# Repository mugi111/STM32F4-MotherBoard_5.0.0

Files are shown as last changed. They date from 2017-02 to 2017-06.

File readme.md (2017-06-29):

### 概要
1. STM32F4-MotherBoard_5.0.0  
STM32F407VGのマザーボード  
回路図，実体配線図
KiCADプロジェクト

2. RCsemiSTM32F4_Ver400
STM32F4MBライブラリ  
使用ライブラリ:SPD(Standard Peripheral Driver)  
使用言語:C

3. RCsemiSTM32F4_Ver500
STM32F4MBライブラリ  
使用ライブラリ:HAL Driver  
使用言語:C++

|STM32F4MB500|個数||
|---|-----|---|
|ADC |1 |BOXHEADER |
|CAN |2 |RJ45 |
|RS232C |2 |RJ12 |
|DisitalIO|2 |BOXHEADER |
|PushSW |1 |DTS-6 |
|RotarySW |1 | |
|LED |1 | |
|MicroSD  |1 | |

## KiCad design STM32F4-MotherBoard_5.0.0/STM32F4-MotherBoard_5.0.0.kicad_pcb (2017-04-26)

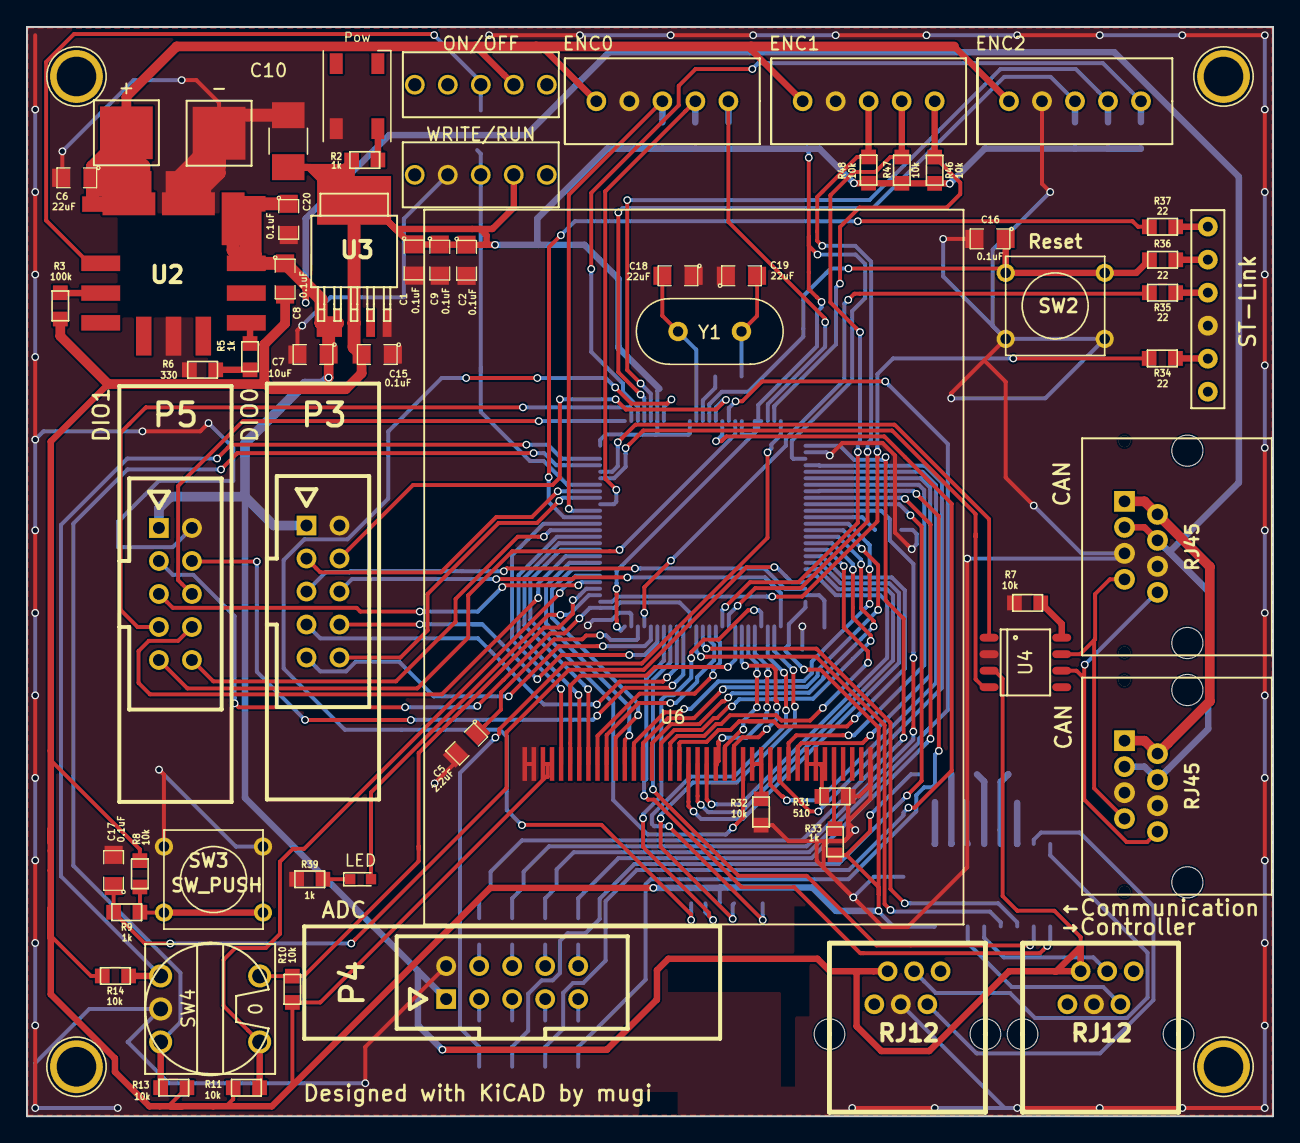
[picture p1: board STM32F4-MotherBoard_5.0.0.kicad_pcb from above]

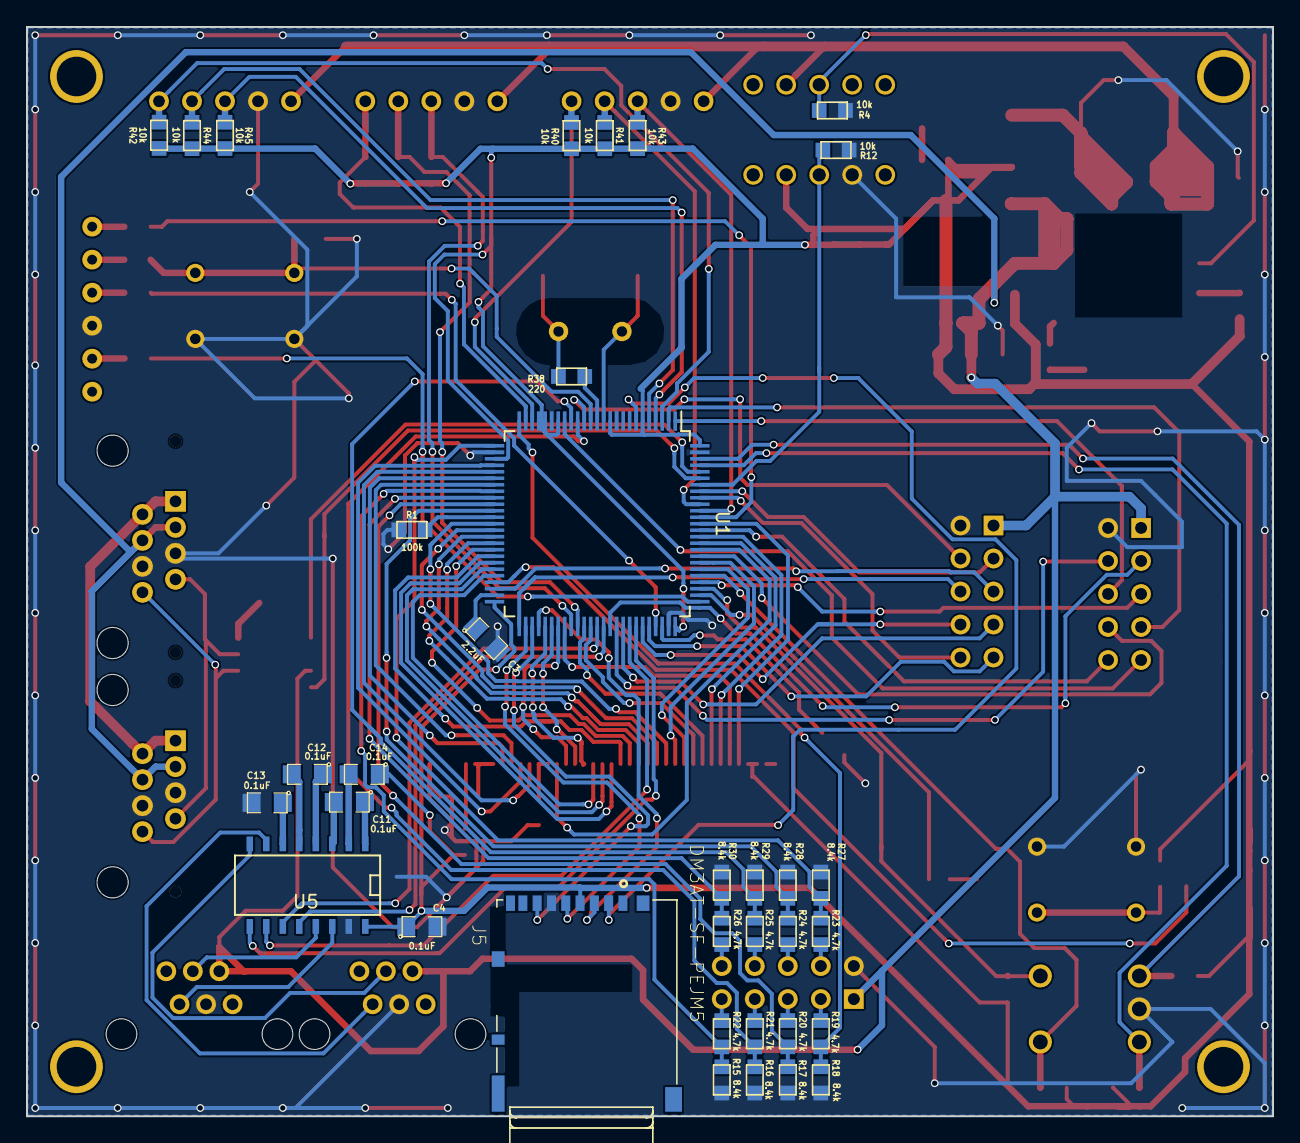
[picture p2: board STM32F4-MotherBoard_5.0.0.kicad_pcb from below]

Board: 2 copper layers, 95.9 x 83.8 mm, 96 parts (35 on the bottom side), 125 nets.

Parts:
+: VCC; 1Pin
-: GND; 1Pin
C1, C2, C4, C8, C9, C11, C12, C13, C14, C15, C16, C17, C20: 0.1uF; SM0805_EXP0.5mm
C3, C5: 2.2uF; SM0805_EXP0.5mm
C6, C18, C19: 22uF; SM0805_EXP0.5mm
C7: 10uF; SM0805_EXP0.5mm
C10: 47uF; C_1210_HandSoldering
CAN: RJ45; 7810-8P8C
CAN#2: RJ45; 7810-8P8C
ENC0: ENC0; XA-5
ENC1: ENC1; XA-5
ENC2: ENC2; XA-5
J5: DM3AT-SF-PEJM5; HRS_DM3AT-SF-PEJM5
LED: LED_0603
ON/OFF: ON/OFF; SW_TOGGLE_5P
P3: DIO0; RA-H101TD
P4: ADC; RA-H101TD
P5: DIO1; RA-H101TD
Pow: Power; LED_WS2812B-PLCC4
R1, R3: 100k; SM0603_EXP0.5mm
R2, R5, R9, R33, R39: 1k; SM0603_EXP0.5mm
R4, R7, R8, R10, R11, R12, R13, R14, R32, R40, R41, R42, R43, R44, R45, R46, R47, R48: 10k; SM0603_EXP0.5mm
R6: 330; SM0603_EXP0.5mm
R15, R16, R17, R18, R27, R28, R29, R30: 8.4k; SM0603_EXP0.5mm
R19, R20, R21, R22, R23, R24, R25, R26: 4.7k; SM0603_EXP0.5mm
R31: 510; SM0603_EXP0.5mm
R34, R35, R36, R37: 22; SM0603_EXP0.5mm
R38: 220; SM0603_EXP0.5mm
ST-Link: SWD; PinHeader-6
SW2: Reset; SW_PUSH
SW3: SW_PUSH
SW4: SW_ROTARY; RotarySW
U1: STM32F407VG; LQFP-100_14x14mm_Pitch0.5mm
U2: OKL-T6-W12
U3: PQ033EZ1H; PQ033EZ1HZ
U4: MCP2551-I/SN; SO-8
U5: ADM3202; SO-16-N
U6: AS021350D; ASO21350D
WRITE/RUN: WRITE/RUN; SW_TOGGLE_5P
Y1: 8MHz; Crystal_HC49-U_Vertical
←Communication: RJ12; MODULAR-JACK_6P6C
→Controller: RJ12; MODULAR-JACK_6P6C

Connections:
+3V3: C1.1, C2.1, C4.1, C8.2, C9.1, C10.2, C14.1, C15.2, J5.4, R2.1, R3.1, R8.1, R10.1, R11.1, R13.1, R14.1, R33.2, R40.1, R41.1, R42.1, R43.1, R44.1, R45.1, R46.1, R47.1, R48.1, U1.6, U1.11, U1.19, U1.21, U1.22, U1.28, U1.50, U1.75, U1.100, U3.3, U5.16, U6.3, U6.4, WRITE/RUN.2
+5V: C7.1, C8.1, C20.1, CAN.3, CAN.4, CAN#2.3, CAN#2.4, P3.1, P4.1, P5.1, U2.4, U2.5, U3.1, U3.2, U4.3, ←Communication.2, →Controller.2
+12V: +.1, C6.1, ENC0.1, ENC1.1, ENC2.1, ON/OFF.4, U2.2
+12VA: CAN.1, CAN.2, CAN#2.1, CAN#2.2
ADC0: R18.1, R19.2, U1.25
ADC1: R23.1, R27.1, U1.26
ADC2: R17.1, R20.2, U1.35
ADC3: R24.1, R28.1, U1.36
ADC4: R16.1, R21.2, U1.16
ADC5: R25.1, R29.1, U1.17
ADC6: R15.1, R22.2, U1.33
ADC7: R26.1, R30.1, U1.34
CAN_RX: U1.95, U4.4
CAN_TX: U1.96, U4.1
CS: U1.88, U6.5
DIO0_0: P3.3, U1.93
DIO0_1: P3.4, U1.15
DIO0_2: P3.5, U1.48
DIO0_3: P3.6, U1.51
DIO0_4: P3.7, U1.67
DIO0_5: P3.8, U1.70
DIO0_6: P3.9, U1.71
DIO0_7: P3.10, U1.92
DIO1_0: P5.3, U1.65
DIO1_1: P5.4, U1.66
DIO1_2: P5.5, U1.79
DIO1_3: P5.6, U1.1
DIO1_4: P5.7, U1.2
DIO1_5: P5.8, U1.83
DIO1_6: P5.9, U1.18
DIO1_7: P5.10, U1.87
ENC0_A: ENC0.3, R43.2, U1.90
ENC0_B: ENC0.4, R41.2, U1.91
ENC0_Z: ENC0.5, R40.2, U1.23
ENC1_A: ENC1.3, R48.2, U1.59
ENC1_B: ENC1.4, R47.2, U1.60
ENC1_Z: ENC1.5, R46.2, U1.24
ENC2_A: ENC2.3, R45.2, U1.4
ENC2_B: ENC2.4, R44.2, U1.5
ENC2_Z: ENC2.5, R42.2, U1.3
FSMC_D0: U1.61, U6.9
FSMC_D1: U1.62, U6.10
FSMC_D2: U1.81, U6.11
FSMC_D3: U1.82, U6.12
FSMC_D4: U1.38, U6.13
FSMC_D5: U1.39, U6.14
FSMC_D6: U1.40, U6.15
FSMC_D7: U1.41, U6.16
FSMC_D8: U1.42, U6.17
FSMC_D9: U1.43, U6.18
FSMC_D10: U1.44, U6.19
FSMC_D11: U1.45, U6.20
FSMC_D12: U1.46, U6.21
FSMC_D13: U1.55, U6.22
FSMC_D14: U1.56, U6.23
FSMC_D15: U1.57, U6.24
GND: -.1, C1.2, C2.2, C3.2, C4.2, C5.2, C6.2, C7.2, C9.2, C10.1, C13.2, C15.1, C16.2, C17.2, C18.1, C19.1, C20.2, CAN.5, CAN.6, CAN#2.5, CAN#2.6, ENC0.2, ENC1.2, ENC2.2, J5.6, P3.2, P4.2, P5.2, Pow.1, R1.2, R4.2, R6.2, R7.2, R12.2, R15.2, R16.2, R17.2, R18.2, R27.2, R28.2, R29.2, R30.2, R31.2, R32.2, R39.2, ST-Link.3, SW2.2, SW3.1, SW4.4, U1.10, U1.20, U1.27, U1.74, U1.99, U2.3, U2.7, U3.5, U4.2, U5.15, U6.1, U6.2, U6.39, WRITE/RUN.4, ←Communication.3, →Controller.3
LED: LED.2, U1.77
NRST: C16.1, R36.1, SW2.1, U1.14
unnamed: C3.1, U1.49
unnamed: C5.1, U1.73
unnamed: C11.1, U5.1
unnamed: C11.2, U5.3
unnamed: C12.1, U5.4
unnamed: C12.2, U5.5
unnamed: C13.1, U5.6
unnamed: C14.2, U5.2
unnamed: C19.2, R38.1, Y1.2
unnamed: Pow.2, R2.2
unnamed: LED.1, R39.1
unnamed: CAN.7, CAN#2.7, U4.7
unnamed: CAN.8, CAN#2.8, U4.6
unnamed: U5.13, →Controller.4
unnamed: U5.14, →Controller.5
unnamed: U5.8, ←Communication.4
unnamed: U5.7, ←Communication.5
unnamed: P4.3, R19.1
unnamed: P4.4, R23.2
unnamed: P4.5, R20.1
unnamed: P4.6, R24.2
unnamed: P4.7, R21.1
unnamed: P4.8, R25.2
unnamed: P4.9, R22.1
unnamed: P4.10, R26.2
unnamed: R34.2, ST-Link.2
unnamed: R35.2, ST-Link.4
unnamed: R36.2, ST-Link.5
unnamed: R37.2, ST-Link.6
unnamed: R1.1, U1.37
unnamed: R3.2, U2.10
unnamed: ON/OFF.3, R4.1, U2.1
unnamed: R5.1, U2.6
unnamed: R5.2, R6.1
unnamed: R7.1, U4.8
unnamed: R8.2, R9.2, SW3.2
unnamed: R31.1, U6.32, U6.33, U6.34
unnamed: R32.1, U6.26, U6.27
unnamed: R33.1, U6.35
OSC_IN: C18.2, U1.12, Y1.1
OSC_OUT: R38.2, U1.13
PushSW: C17.1, R9.1, U1.47
RD: U1.85, U6.8
RS: U1.58, U6.6
RS-232(Controller)_RX: U1.64, U5.12
RS-232(Controller)_TX: U1.63, U5.11
RS-232(PC)_RX: U1.69, U5.9
RS-232(PC)_TX: U1.68, U5.10
RST: U1.84, U6.25
RotarySW0: R10.2, SW4.1, U1.78
RotarySW1: R11.2, SW4.2, U1.80
RotarySW2: R13.2, SW4.3, U1.97
RotarySW3: R14.2, SW4.5, U1.98
SPI_CS: J5.2, U1.7
SPI_MISO: J5.7, U1.53
SPI_MOSI: J5.3, U1.54
SPI_SCK: J5.5, U1.52
SWCLK: R34.1, U1.76
SWDIO: R35.1, U1.72
SWO: R37.1, U1.89
WR: U1.86, U6.7
Write: R12.1, U1.94, WRITE/RUN.3
XL: U1.29, U6.29
XR: U1.31, U6.31
YB: U1.30, U6.28
YT: U1.32, U6.30

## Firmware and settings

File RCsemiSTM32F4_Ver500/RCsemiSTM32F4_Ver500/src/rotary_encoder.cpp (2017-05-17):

/*
 * rotary_encoder.cpp
 *
 *  Created on: 2017/03/07
 *      Author: mugi111
 */

#include "rotary_encoder.h"
#include <stm32f4xx_hal.h>
#include <stm32f4xx_hal_rcc.h>
#include <stm32f4xx_hal_gpio.h>
#include <stm32f4xx_hal_tim.h>

namespace RCsemi{

	rotary_encoder::rotary_encoder(int ch)
	{
		m_ch = ch;

		if(ch == 0){
			__HAL_RCC_GPIOB_CLK_ENABLE();
			__HAL_RCC_TIM3_CLK_ENABLE();

			GPIO_InitTypeDef GPIO_InitStructure;
			GPIO_InitStructure.Mode = GPIO_MODE_AF_PP;
			GPIO_InitStructure.Pin = GPIO_PIN_4 | GPIO_PIN_5;
			GPIO_InitStructure.Pull = GPIO_NOPULL;
			GPIO_InitStructure.Speed = GPIO_SPEED_FREQ_VERY_HIGH;
			GPIO_InitStructure.Alternate = GPIO_AF2_TIM3;

			HAL_GPIO_Init(GPIOB, &GPIO_InitStructure);

			TIM_Encoder_InitTypeDef Encoder_InitStructure;
			Encoder_InitStructure.EncoderMode = TIM_ENCODERMODE_TI12;
			Encoder_InitStructure.IC1Filter = 0;
			Encoder_InitStructure.IC1Polarity = TIM_ICPOLARITY_RISING;
			Encoder_InitStructure.IC1Selection = TIM_ICSELECTION_DIRECTTI;
			Encoder_InitStructure.IC1Prescaler = TIM_ICPSC_DIV1;
			Encoder_InitStructure.IC2Filter = 0;
			Encoder_InitStructure.IC2Polarity = TIM_ICPOLARITY_RISING;
			Encoder_InitStructure.IC2Selection = TIM_ICSELECTION_DIRECTTI;
			Encoder_InitStructure.IC2Prescaler = TIM_ICPSC_DIV1;

			TIM_HandleTypeDef htim3;
			htim3.Instance = TIM3;
			htim3.Init.Prescaler = 0;
			htim3.Init.CounterMode = TIM_COUNTERMODE_UP;
			htim3.Init.Period = 0;
			htim3.Init.ClockDivision = TIM_CLOCKDIVISION_DIV1;

			HAL_TIM_Encoder_Init(&htim3, &Encoder_InitStructure);
			HAL_TIM_Encoder_Start(&htim3, TIM_CHANNEL_ALL);

		}else if(ch == 1){
			__HAL_RCC_GPIOD_CLK_ENABLE();
			__HAL_RCC_TIM4_CLK_ENABLE();

			GPIO_InitTypeDef GPIO_InitStructure;
			GPIO_InitStructure.Mode = GPIO_MODE_AF_PP;
			GPIO_InitStructure.Pin = GPIO_PIN_12 | GPIO_PIN_13;
			GPIO_InitStructure.Pull = GPIO_NOPULL;
			GPIO_InitStructure.Speed = GPIO_SPEED_FREQ_VERY_HIGH;
			GPIO_InitStructure.Alternate = GPIO_AF2_TIM4;

			HAL_GPIO_Init(GPIOD, &GPIO_InitStructure);

			TIM_Encoder_InitTypeDef Encoder_InitStructure;
			Encoder_InitStructure.EncoderMode = TIM_ENCODERMODE_TI12;
			Encoder_InitStructure.IC1Filter = 0;
			Encoder_InitStructure.IC1Polarity = TIM_ICPOLARITY_RISING;
			Encoder_InitStructure.IC1Selection = TIM_ICSELECTION_DIRECTTI;
			Encoder_InitStructure.IC1Prescaler = TIM_ICPSC_DIV1;
			Encoder_InitStructure.IC2Filter = 0;
			Encoder_InitStructure.IC2Polarity = TIM_ICPOLARITY_RISING;
			Encoder_InitStructure.IC2Selection = TIM_ICSELECTION_DIRECTTI;
			Encoder_InitStructure.IC2Prescaler = TIM_ICPSC_DIV1;


			TIM_HandleTypeDef htim4;
			htim4.Instance = TIM4;
			htim4.Init.Prescaler = 0;
			htim4.Init.CounterMode = TIM_COUNTERMODE_UP;
			htim4.Init.Period = 0;
			htim4.Init.ClockDivision = TIM_CLOCKDIVISION_DIV1;

			HAL_TIM_Encoder_Init(&htim4, &Encoder_InitStructure);
			HAL_TIM_Encoder_Start(&htim4, TIM_CHANNEL_ALL);

		}else if(ch == 2){
			__HAL_RCC_GPIOE_CLK_ENABLE();
			__HAL_RCC_TIM9_CLK_ENABLE();

			GPIO_InitTypeDef GPIO_InitStructure;
			GPIO_InitStructure.Mode = GPIO_MODE_AF_PP;
			GPIO_InitStructure.Pin = GPIO_PIN_5 | GPIO_PIN_6;
			GPIO_InitStructure.Pull = GPIO_NOPULL;
			GPIO_InitStructure.Speed = GPIO_SPEED_FREQ_VERY_HIGH;
			GPIO_InitStructure.Alternate = GPIO_AF3_TIM9;

			HAL_GPIO_Init(GPIOE, &GPIO_InitStructure);

			TIM_Encoder_InitTypeDef Encoder_InitStructure;
			Encoder_InitStructure.EncoderMode = TIM_ENCODERMODE_TI12;
			Encoder_InitStructure.IC1Filter = 0;
			Encoder_InitStructure.IC1Polarity = TIM_ICPOLARITY_RISING;
			Encoder_InitStructure.IC1Selection = TIM_ICSELECTION_DIRECTTI;
			Encoder_InitStructure.IC1Prescaler = TIM_ICPSC_DIV1;
			Encoder_InitStructure.IC2Filter = 0;
			Encoder_InitStructure.IC2Polarity = TIM_ICPOLARITY_RISING;
			Encoder_InitStructure.IC2Selection = TIM_ICSELECTION_DIRECTTI;
			Encoder_InitStructure.IC2Prescaler = TIM_ICPSC_DIV1;


			TIM_HandleTypeDef htim9;
			htim9.Instance = TIM9;
			htim9.Init.Prescaler = 0;
			htim9.Init.CounterMode = TIM_COUNTERMODE_UP;
			htim9.Init.Period = 0;
			htim9.Init.ClockDivision = TIM_CLOCKDIVISION_DIV1;

			HAL_TIM_Encoder_Init(&htim9, &Encoder_InitStructure);
			HAL_TIM_Encoder_Start(&htim9, TIM_CHANNEL_ALL);

		}else{
//#error "そんなポートはないよ"
		}
	}

	inline int rotary_encoder::getCount()
	{
		if(m_ch == 0){
			return (signed short)TIM3->CNT;
		}else if(m_ch == 1){
			return (signed short)TIM4->CNT;
		}else if(m_ch == 2){
			return (signed short)TIM9->CNT;
		}else{
			return 0;
		}
	}

	inline void rotary_encoder::clearCount()
	{
		if(m_ch == 0){
			TIM3->CNT = 0;
		}else if(m_ch == 1){
			TIM4->CNT = 0;
		}else if(m_ch == 2){
			TIM9->CNT = 0;
		}else{

		}
	}
}

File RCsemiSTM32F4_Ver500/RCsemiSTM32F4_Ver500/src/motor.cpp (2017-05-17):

/*
 * motor.cpp
 *
 *  Created on: 2017/04/25
 *      Author: mugi111
 */

#include "motor.h"

#define DUTY_TO_DIR(duty) ((duty) == BRAKEVALUE	? 0x03 : \
						   (duty) < 0			? 0x02 : \
						   (duty) > 0	 		? 0x01 : 0x00)

#define ABS_VAL(val) ((val) < 0 ? -(val) : (val))

#define IS_SHORTCURRENT_PATTERN(dir_now, dir_old)	((dir_now) != (dir_old) && (dir_now) && (dir_old))

namespace RCsemi{

_motor_status_t gMotor_status[3] = {{{0}}};

motor::motor(unsigned short ch)
{
	m_currentDuty = 0;
	m_ch = ch;


}

int motor::drive(int duty)
{
	uint8_t port = m_ch>>2;	// 0:0-3 / 1:4-7
	m_ch &= 0x02; 		// 0-2に制限

	uint8_t dir_now = DUTY_TO_DIR(duty);
	uint8_t dir_old = gMotor_status[port].dir_old[m_ch];

	if(gMotor_status[port].isEnable[m_ch])	gMotor_status[port].duty[m_ch] = ABS_VAL(duty);
	else									gMotor_status[port].duty[m_ch] = 0;

	/****************************	貫通電流対策	***********************************/
	if(gMotor_status[port].deadtime[m_ch])
	{
		if(IS_SHORTCURRENT_PATTERN(dir_now, dir_old))
		{
			gMotor_status[port].dir_save[m_ch] = dir_now;
		}
		else
		{
			gMotor_status[port].deadtime[m_ch] = 0;
			gMotor_status[port].dir		[m_ch] = dir_now;
			gMotor_status[port].dir_old [m_ch] = dir_now;
		}
	}
	else
	{
		if(IS_SHORTCURRENT_PATTERN(dir_now, dir_old))
		{
			gMotor_status[port].deadtime[m_ch] = MOTOR_DEADTIME_10US;
			gMotor_status[port].dir		[m_ch] = 0;
			gMotor_status[port].dir_save[m_ch] = dir_now;
		}
		else
		{
			gMotor_status[port].dir	   [m_ch] = dir_now;
			gMotor_status[port].dir_old[m_ch] = dir_now;
		}
	}
	/******************************************************************************/


	m_currentDuty = duty;
	return duty;
}

bool motor::brake()
{
	drive(BRAKEVALUE);

	return true;
//	return false;
}

int motor::getCurrentDuty()
{
	return m_currentDuty;
}


}

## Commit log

2017-02-08 シート作成
    [CAN.sch, DIO-ADC.sch, Display.sch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]
2017-02-08 readme更新
2017-02-08 だいたい確定
    [pinasign.xlsx]
2017-02-08 シート追加
    [STM32F4-MotherBoard_4.0.0.sch]
2017-02-11 機能名の変更
    [pinasign.xlsx]
2017-02-11 ラベルの作成
    [STM32F4-MotherBoard_4.0.0.sch]
2017-02-11 add LED
    [power.sch]
2017-02-11 add run write
    [STM32F4-MotherBoard_5.0.0.sch, SW.sch]
2017-02-11 ラベル方向設定
    [DIO-ADC.sch, OSC.sch, RS-232.sch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]
2017-02-11 大枠の電源
    [STM32F4-MotherBoard_5.0.0.sch]
2017-02-14 SDとCANの追加とラベルミス修正
    [CAN.sch, DIO-ADC.sch, Display.sch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]
2017-02-16 回路図終わり
    [CAN.sch, DIO-ADC.sch, Display.sch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]
2017-02-16 部品名変更
    [CAN.sch, DIO-ADC.sch, Display.sch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]
2017-02-16 CSピン追加
    [pinasign.xlsx]
2017-02-19 関連付けできたの
    [CAN.sch, DIO-ADC.sch, Display.sch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]
2017-02-19 部品配置
    [Display.sch, STM32F4-MotherBoard_5.0.0.kicad_pcb, STM32F4-MotherBoard_5.0.0.sch]
2017-02-28 部品配置終わり
    [CAN.sch, STM32F4-MotherBoard_5.0.0.kicad_pcb]
2017-03-07 部品配置再考終わり
    [STM32F4-MotherBoard_5.0.0.kicad_pcb]
2017-04-20 add timerClass
2017-04-24 change timer.cpp
2017-04-25 add motor
2017-04-26 add Garver
    [STM32F4-MotherBoard_5.0.0-B.Cu.gbr, STM32F4-MotherBoard_5.0.0-B.Mask.gbr, STM32F4-MotherBoard_5.0.0-B.SilkS.gbr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]
2017-04-26 replace project
    [CAN.sch, DIO-ADC.sch, Display.sch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]
2017-04-27 なんか変わった
2017-04-27 何が変わったかわからない
2017-04-27 コンストラクタの追加
2017-04-27 コンストラクタの追加したりしなかったり
2017-05-03 自由に使えるやつのあれの外枠を追加
2017-05-03 インデント直した
2017-05-03 仕様変わりすぎてたからちょっと保留
2017-05-03 SPDからHALへの変更でIRQHandlerを消した
2017-05-03 motor driveの中身追加した
2017-05-16 digitalIOピン変更
2017-05-16 LEDとPushSWの変更に伴う引数の削除
2017-05-17 MB関数変更(LED)
2017-05-17 fatfs追加
2017-05-17 example追加main削除
2017-05-17 example中身
2017-05-17 readme書き加え
2017-05-17 表書き換え
2017-05-17 readme書き換え
2017-05-17 includeかわった
2017-05-17 なんかわからない
2017-05-20 うごくといいな
2017-05-20 exampleヘッダー書き換え CAN example一時削除
2017-05-20 exampleヘッダー対応
2017-05-20 exampleヘッダー書き換え
2017-05-20 CAN_Motor_Drive書いたけど動く気がしない
2017-05-20 アドレスに関して書き換え
2017-05-20 引数type追加
2017-05-20 適当にDIOも
2017-06-02 スペルミス修正
2017-06-03 ほとんどの機能試せた
2017-06-03 MDの引数を構造体に
2017-06-19 初期化成功するようになった
2017-06-23 loopback成功
2017-06-29 readme修正
2017-06-29 SendFrameの関数名，引数名の変更とテスト用loopbackのプログラム削除
2017-06-29 CAN関連の関数名引数名の変更とFrameMode(REMOTE, DATA)を選択できるように
2017-06-29 CAN非常停止関数の引数を列挙型に
2017-06-29 CAN:関数が複雑になるためFilterConfig関数の削除と仮想的なMasterとしてのフィルター設定をInit関数内でするように変更
2017-06-29 DIOの状態を要求する関数を書いたがデータの受取に関して考える必要があるためコメントアウトそれに伴ったOutput関数の変更
2017-07-10 change sample
